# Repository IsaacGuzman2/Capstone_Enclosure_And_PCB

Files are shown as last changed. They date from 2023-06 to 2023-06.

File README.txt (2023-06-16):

Hi future student!

IF you are reading this congrats you get to continue a cool project that I had the pleasure of getting to start for my capstone.

This folder contains the enclosures and PCB files that I made for this project. I was mainly in charge of the more physical aspects of this project so any questions about that you can contact me about through my school email (guzmange@oregonstate.edu) 

I'd be more then happy to help with any questions. This stuff is free use so don't be afraid to delete, add, or modify in any way you see fit. I understand you will have to make your own engineering requirements so go off I guess. 

I wish you the best in this project don't forget to communicate with Gerrad he has some good ideas and even is really motivating. This project has some real impact so be proud of what you accomplish and relly try your best and you will be rewarded by making a positive impact in the world. 

Godspeed homies

Gerardo Isaac Guzman

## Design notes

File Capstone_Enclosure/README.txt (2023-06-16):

Hi future student! My name is Gerardo Isaac Guzman

This folder here is the solidwork files for the main enclosure that houses the microcontroller and the battery

The enclousure is printed in parts

1x bottom piece
2x latches
1x lid
1x seal

Almost all pieces are printed in PETG except for the seal which is printed in TPU

Settings for PETG
-> Temp: 230 C
-> Bed Temp: 75 C
A quick google search or youtube video for more advanced setting parameters if you want to get technical.

TPU has similar settings with a lower bed temp. I also reccommend looking up the parameters like PETG to get a more advanced print

You should be able to export the STL files for printing through solidworks. I also wanted to give you just the solid works files so you can add your own holes and other features to meet that engineering requirment quota. My group wanted to make sure you can finish the main project while still meeting the class requirements. That way capstone should be a little easier. I hope this document helps and good luck on the project, my group had a lot of fun with it and we hope you can have as much fun as well. 

Godspeed homies,

Gerardo Isaac Guzman

Email: guzmange@oregonstate.edu

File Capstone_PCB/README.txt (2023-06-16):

Hi again future student!

This here is the Kicad Project files for the Main PCB 

This PCB has the schematic and pcb files for the project as well as a folder for the gerber files to get our final version of the PCB printed by OSHPark

There should also be a .csv file here with the BOM that should help find which parts are needed in case something happens with carrying over the files. 

I HIGHLY reccomend ordering at another PCB print shop other then OSHPark because of the cost. It is a 2-layer board but it costs about $45+ with no rushed shipping (12-15 days) so it can get expensive. Please look at other options when ordering if money is an issue. 

Hopefully this file helps as always fell free to make adjustments to meet the capstone class requirements. 

Godspeed homies,

Gerardo Isaac Guzman

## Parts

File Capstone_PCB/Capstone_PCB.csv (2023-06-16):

Source: | D:\ECE441\Lab3\Capstone_PCB\Capstone_PCB.kicad_sch
Date: | 4/28/2023 10:56:03 PM
Tool: | Eeschema (6.0.8)
Generator: | D:\ECE441\Software\KiCad\6.0\bin\scripting\plugins/bom_csv_grouped_by_value.py
Component Count: | 38
Individual Components:
Item | Qty | Reference(s) | Value | LibPart | Footprint | Datasheet | MANUFACTURER | MAXIMUM_PACKAGE_HEIGHT | PARTREV | STANDARD
 |  | BATT1 | JST 2PH | Adafruit_BQ24074-eagle-import:JST_2PIN-SMT-RA | Adafruit_BQ24074:JST-PH-2-SMT-RA
 |  | C1 | 10uF | Device:C | Capacitor_SMD:C_0805_2012Metric | ~
 |  | C2 | 10uF | Device:C | Capacitor_SMD:C_0805_2012Metric | ~
 |  | C3 | 10UF | Device:C | Capacitor_SMD:C_0805_2012Metric | ~
 |  | C4 | 10UF | Device:C | Capacitor_SMD:C_0805_2012Metric | ~
 |  | C5 | 10UF | Device:C | Capacitor_SMD:C_0805_2012Metric | ~
 |  | C6 | 10UF | Device:C | Capacitor_SMD:C_0805_2012Metric | ~
 |  | C7 | 10UF | Device:C | Capacitor_SMD:C_0805_2012Metric | ~
 |  | D1 | SK34A | SK34A:SK34A | SK34A:DIOM4325X250N |  | Taiwan Semiconductor | 2.5 mm | O2102 | IPC-7351B
 |  | D2 | LED | Device:LED | LED_SMD:LED_0603_1608Metric | ~
 |  | D3 | LED | Device:LED | LED_SMD:LED_0603_1608Metric | ~
 |  | D4 | SK34A | SK34A:SK34A | SK34A:DIOM4325X250N |  | Taiwan Semiconductor | 2.5 mm | O2102 | IPC-7351B
 |  | H1 | MountingHole_Pad | Mechanical:MountingHole_Pad | MountingHole:MountingHole_2.2mm_M2_ISO14580_Pad | ~
 |  | H2 | MountingHole_Pad | Mechanical:MountingHole_Pad | MountingHole:MountingHole_2.2mm_M2_ISO14580_Pad | ~
 |  | J1 | RJ45 | Connector:RJ45 | Connector_RJ:RJ45_OST_PJ012-8P8CX_Vertical | ~
 |  | J2 | 2.1MM DC | Connector:Barrel_Jack_Switch | Connector_BarrelJack:BarrelJack_CLIFF_FC681465S_SMT_Horizontal | ~
 |  | J3 | RJ45 | Connector:RJ45 | Connector_RJ:RJ45_OST_PJ012-8P8CX_Vertical | ~
 |  | JP1 | SolderJumper_3_Bridged12 | Jumper:SolderJumper_3_Bridged12 | Jumper:SolderJumper-3_P1.3mm_Bridged12_RoundedPad1.0x1.5mm_NumberLabels | ~
 |  | JP2 | SolderJumper_3_Bridged12 | Jumper:SolderJumper_3_Bridged12 | Jumper:SolderJumper-3_P1.3mm_Bridged12_RoundedPad1.0x1.5mm | ~
 |  | JP3 | 1.5A | Jumper:SolderJumper_2_Open | Jumper:SolderJumper-2_P1.3mm_Open_TrianglePad1.0x1.5mm | ~
 |  | JP4 | 1.0A | Jumper:SolderJumper_2_Open | Jumper:SolderJumper-2_P1.3mm_Bridged_Pad1.0x1.5mm | ~
 |  | JP5 | 0.5A | Jumper:SolderJumper_2_Open | Jumper:SolderJumper-2_P1.3mm_Open_TrianglePad1.0x1.5mm | ~
 |  | JP6 | THERM | Jumper:SolderJumper_2_Open | Jumper:SolderJumper-2_P1.3mm_Bridged_RoundedPad1.0x1.5mm | ~
 |  | R1 | 10K | Device:R_Small_US | Resistor_SMD:R_0603_1608Metric | ~
 |  | R2 | 10K | Device:R_Small_US | Resistor_SMD:R_0603_1608Metric | ~
 |  | R3 | 1K | Device:R_Small_US | Resistor_SMD:R_0603_1608Metric | ~
 |  | R4 | 5.1K | Device:R_US | Resistor_SMD:R_0603_1608Metric | ~
 |  | R5 | 590 | Device:R_Small_US | Resistor_SMD:R_0603_1608Metric | ~
 |  | R6 | 1K | Device:R_Small_US | Resistor_SMD:R_0603_1608Metric | ~
 |  | R7 | 5.1K | Device:R_US | Resistor_SMD:R_0603_1608Metric | ~
 |  | R8 | 2K | Device:R_Small_US | Resistor_SMD:R_0603_1608Metric | ~
 |  | R9 | 10K | Device:R_Small_US | Resistor_SMD:R_0603_1608Metric | ~
 |  | R10 | 10K | Device:R_Small_US | Resistor_SMD:R_0603_1608Metric | ~
 |  | R11 | 10K | Device:R_Small_US | Resistor_SMD:R_0603_1608Metric | ~
 |  | SYSOUT1 | JST 2PH | Adafruit_BQ24074-eagle-import:JST_2PIN-SMT-RA | Adafruit_BQ24074:JST-PH-2-SMT-RA
 |  | U1 | BQ24074RGT | Battery_Management:BQ24074RGT | Package_DFN_QFN:VQFN-16-1EP_3x3mm_P0.5mm_EP1.6x1.6mm | http://www.ti.com/lit/ds/symlink/bq24074.pdf
 |  | X1 | USB Type C | Adafruit_BQ24074-eagle-import:USB_C | Adafruit_BQ24074:USB_C_CUSB31-CFM2AX-01-X
 |  | XA1 | Arduino_MKR_NB_1500_Socket | Arduino_Library:Arduino_MKR_NB_1500_Socket | Arduino_Library:Arduino_MKR_FOX_1200_Socket | https://docs.arduino.cc/hardware/mkr-nb-1500
Collated Components:
Item | Qty | Reference(s) | Value | LibPart | Footprint | Datasheet | MANUFACTURER | MAXIMUM_PACKAGE_HEIGHT | PARTREV | STANDARD
1 | 2 | BATT1, SYSOUT1 | JST 2PH | Adafruit_BQ24074-eagle-import:JST_2PIN-SMT-RA | Adafruit_BQ24074:JST-PH-2-SMT-RA
2 | 2 | C1, C2 | 10uF | Device:C | Capacitor_SMD:C_0805_2012Metric | ~
3 | 5 | C3, C4, C5, C6, C7 | 10UF | Device:C | Capacitor_SMD:C_0805_2012Metric | ~
4 | 2 | D1, D4 | SK34A | SK34A:SK34A | SK34A:DIOM4325X250N |  | Taiwan Semiconductor | 2.5 mm | O2102 | IPC-7351B
5 | 2 | D2, D3 | LED | Device:LED | LED_SMD:LED_0603_1608Metric | ~
6 | 2 | H1, H2 | MountingHole_Pad | Mechanical:MountingHole_Pad | MountingHole:MountingHole_2.2mm_M2_ISO14580_Pad | ~
7 | 2 | J1, J3 | RJ45 | Connector:RJ45 | Connector_RJ:RJ45_OST_PJ012-8P8CX_Vertical | ~
8 | 1 | J2 | 2.1MM DC | Connector:Barrel_Jack_Switch | Connector_BarrelJack:BarrelJack_CLIFF_FC681465S_SMT_Horizontal | ~
9 | 1 | JP1 | SolderJumper_3_Bridged12 | Jumper:SolderJumper_3_Bridged12 | Jumper:SolderJumper-3_P1.3mm_Bridged12_RoundedPad1.0x1.5mm_NumberLabels | ~
10 | 1 | JP2 | SolderJumper_3_Bridged12 | Jumper:SolderJumper_3_Bridged12 | Jumper:SolderJumper-3_P1.3mm_Bridged12_RoundedPad1.0x1.5mm | ~
11 | 1 | JP3 | 1.5A | Jumper:SolderJumper_2_Open | Jumper:SolderJumper-2_P1.3mm_Open_TrianglePad1.0x1.5mm | ~
12 | 1 | JP4 | 1.0A | Jumper:SolderJumper_2_Open | Jumper:SolderJumper-2_P1.3mm_Bridged_Pad1.0x1.5mm | ~
13 | 1 | JP5 | 0.5A | Jumper:SolderJumper_2_Open | Jumper:SolderJumper-2_P1.3mm_Open_TrianglePad1.0x1.5mm | ~
14 | 1 | JP6 | THERM | Jumper:SolderJumper_2_Open | Jumper:SolderJumper-2_P1.3mm_Bridged_RoundedPad1.0x1.5mm | ~
15 | 5 | R1, R2, R9, R10, R11 | 10K | Device:R_Small_US | Resistor_SMD:R_0603_1608Metric | ~
16 | 2 | R3, R6 | 1K | Device:R_Small_US | Resistor_SMD:R_0603_1608Metric | ~
17 | 2 | R4, R7 | 5.1K | Device:R_US | Resistor_SMD:R_0603_1608Metric | ~
18 | 1 | R5 | 590 | Device:R_Small_US | Resistor_SMD:R_0603_1608Metric | ~
19 | 1 | R8 | 2K | Device:R_Small_US | Resistor_SMD:R_0603_1608Metric | ~
20 | 1 | U1 | BQ24074RGT | Battery_Management:BQ24074RGT | Package_DFN_QFN:VQFN-16-1EP_3x3mm_P0.5mm_EP1.6x1.6mm | http://www.ti.com/lit/ds/symlink/bq24074.pdf
21 | 1 | X1 | USB Type C | Adafruit_BQ24074-eagle-import:USB_C | Adafruit_BQ24074:USB_C_CUSB31-CFM2AX-01-X
22 | 1 | XA1 | Arduino_MKR_NB_1500_Socket | Arduino_Library:Arduino_MKR_NB_1500_Socket | Arduino_Library:Arduino_MKR_FOX_1200_Socket | https://docs.arduino.cc/hardware/mkr-nb-1500

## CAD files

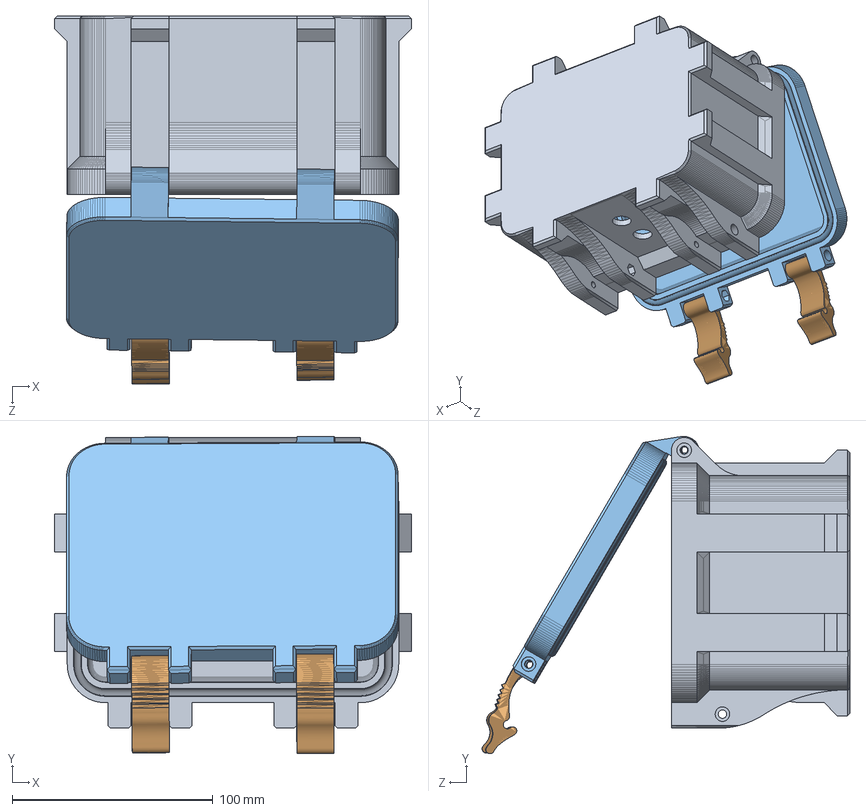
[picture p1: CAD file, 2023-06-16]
Capstone_Enclosure/Assem1.SLDASM
178.1 x 158.3 x 183.5 mm
Enclosure
Enclosure_Latch x 2
LID

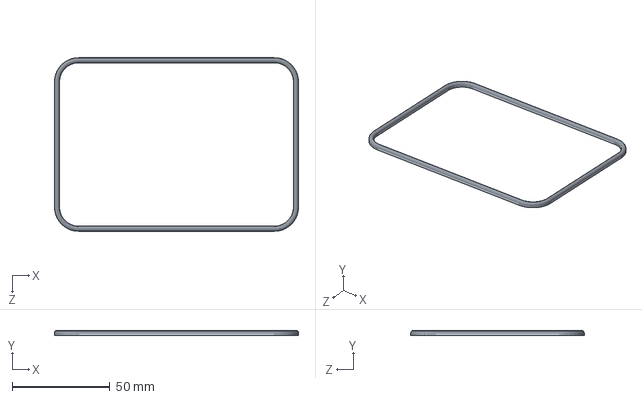
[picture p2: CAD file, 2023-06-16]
Capstone_Enclosure/SEAL.SLDPRT
124.6 x 2.80 x 88.6 mm

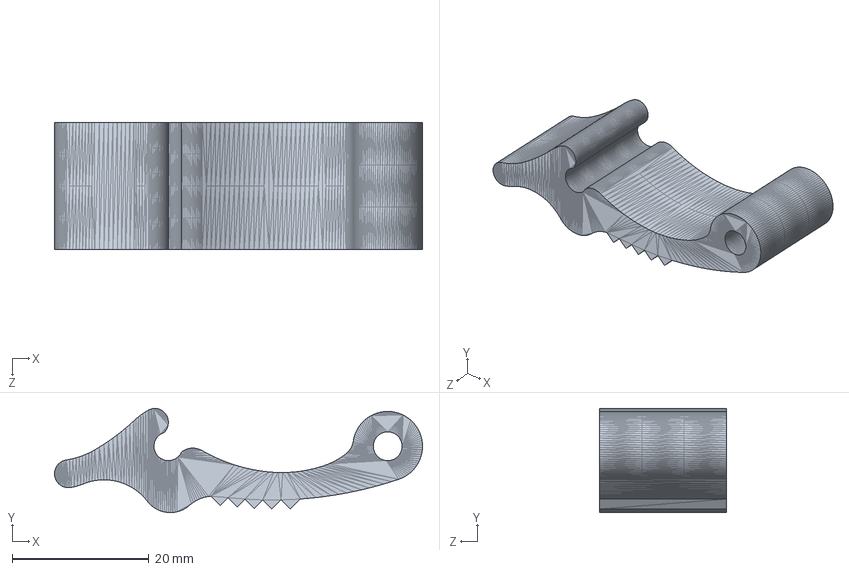
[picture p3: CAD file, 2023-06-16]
Capstone_Enclosure/Enclosure_Latch.SLDPRT
53.8 x 15.2 x 18.6 mm

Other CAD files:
Veloity Sensor Enclosure/VLCTY_SNSR_ENCL.f3d

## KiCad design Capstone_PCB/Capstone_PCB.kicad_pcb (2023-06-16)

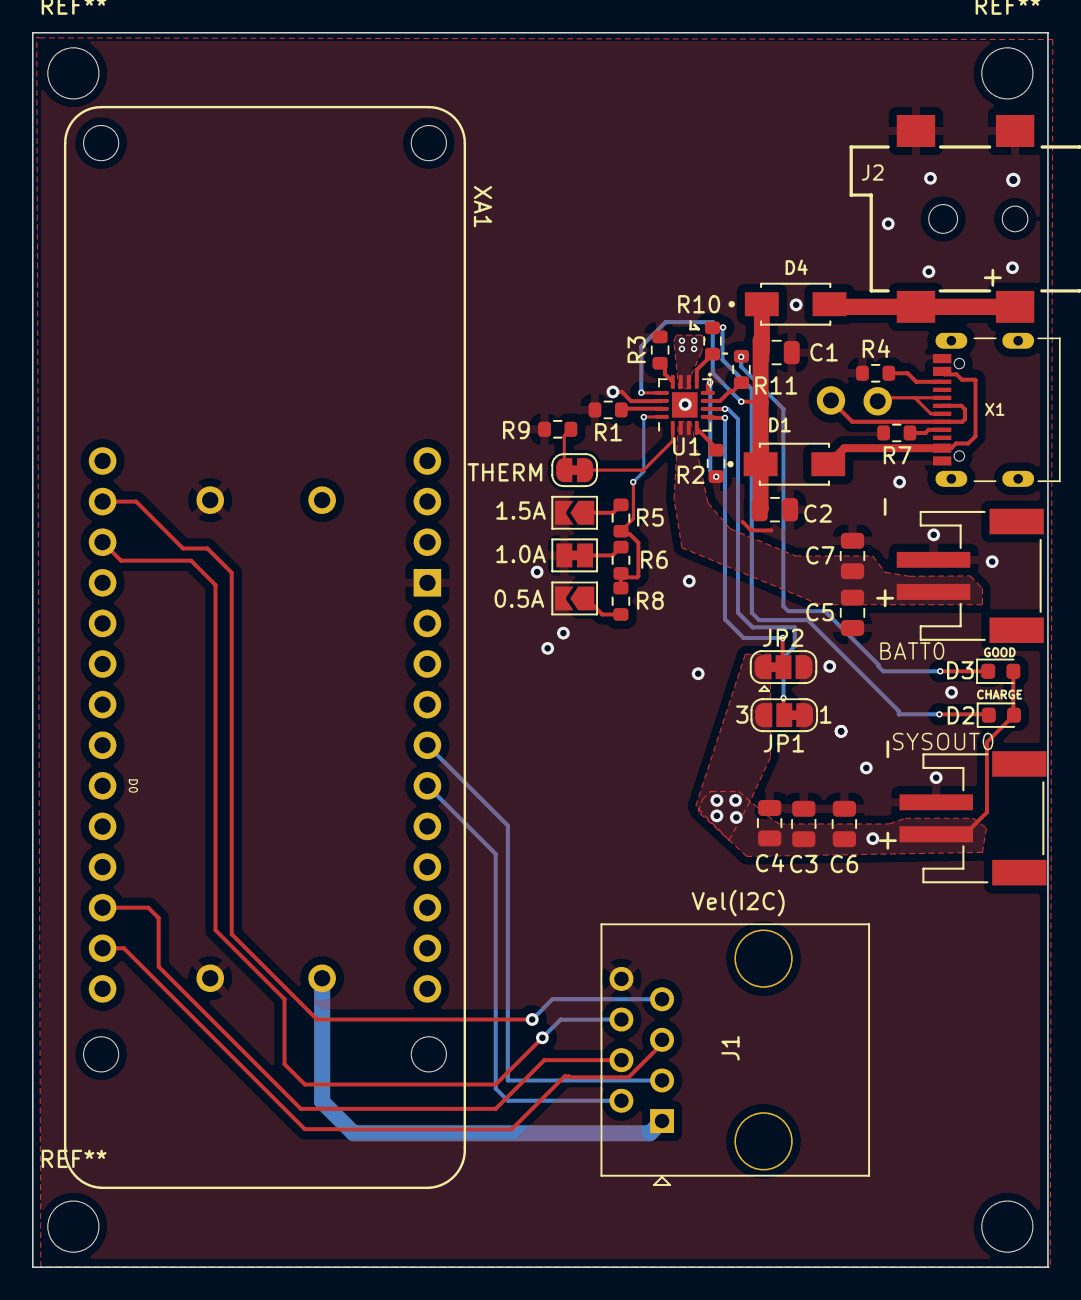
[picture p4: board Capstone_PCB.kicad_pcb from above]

Board: 2 copper layers, 63.5 x 77.2 mm, 35 parts (0 on the bottom side), 31 nets.

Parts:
BATT0: JST 2PH; JST-PH-2-SMT-RA
C1, C2: 10uF; C_0805_2012Metric
C3, C4, C5, C6, C7: 10UF; C_0805_2012Metric
D1, D4: SK34A; DIOM4325X250N
D2, D3: LED; LED_0603_1608Metric
J1: RJ45; RJ45_OST_PJ012-8P8CX_Vertical
J2: 2.1mm DC; DCJACK_2MM_SMT
JP1: SolderJumper_3_Bridged12; SolderJumper-3_P1.3mm_Bridged12_RoundedPad1.0x1.5mm_NumberL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
JP2: SolderJumper_3_Bridged12; SolderJumper-3_P1.3mm_Bridged12_RoundedPad1.0x1.5mm
JP3: 1.5A; SolderJumper-2_P1.3mm_Open_TrianglePad1.0x1.5mm
JP4: 1.0A; SolderJumper-2_P1.3mm_Bridged_Pad1.0x1.5mm
JP5: 0.5A; SolderJumper-2_P1.3mm_Open_TrianglePad1.0x1.5mm
JP6: THERM; SolderJumper-2_P1.3mm_Bridged_RoundedPad1.0x1.5mm
R1, R2, R9, R10, R11: 10K; R_0603_1608Metric
R3, R6: 1K; R_0603_1608Metric
R4, R7: 5.1K; R_0603_1608Metric
R5: 590; R_0603_1608Metric
R8: 2K; R_0603_1608Metric
SYSOUT0: JST 2PH; JST-PH-2-SMT-RA
U1: BQ24074RGT; VQFN-16-1EP_3x3mm_P0.5mm_EP1.6x1.6mm
X1: USB Type C; USB_C_CUSB31-CFM2AX-01-X
XA1: Arduino_MKR_NB_1500_Socket; Arduino_MKR_FOX_1200_Socket

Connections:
/A0: J1.7, XA1.A0 (A0/DAC)
/A1: J1.6, XA1.A1
/CC1: R7.1, X1.A5
/CC2: R4.1, X1.B5
/CE: R2.1, U1.4 (~CE)
/CHARGE: R10.2, U1.9 (~CHG)
/D3: J1.4, XA1.D3
/D4: J1.5, XA1.D4
/D+: X1.A6, X1.B6
/D-: X1.A7, X1.B7
/EN1: JP1.2 (C), U1.6 (EN1)
/EN2: JP2.2 (C), U1.5 (EN2)
/GOOD: R11.1, U1.7 (~PGOOD)
/ILIM: R3.1, U1.12 (ILIM)
/ISET: R5.1, R6.1, R8.1, U1.16 (ISET)
/ITERM: R1.1, U1.15 (ITERM)
/LIPO: BATT0.1, C5.1, C7.1, U1.2 (BAT), U1.3 (BAT)
/OUT: C3.1, C4.1, C6.1, D2.2 (A), D3.2 (A), J1.1, JP1.3 (B), JP2.1 (A), SYSOUT0.1, U1.10 (OUT), U1.11 (OUT), XA1.VIN
/SCL: J1.3, XA1.D12 (D12_SCL)
/SDA: J1.2, XA1.D11 (D11_SDA)
/TS: JP6.2 (B), U1.1 (TS)
/VIN: C1.1, C2.1, D1.C, D4.C, U1.13 (IN)
/VUSB: D1.A, X1.A4B9, X1.B4A9
GND: BATT0.2, C1.2, C2.2, C3.2, C4.2, C5.2, C6.2, C7.2, J1.8, J2.2, J2.3, JP1.1 (A), JP2.3 (B), JP3.2 (B), JP4.2 (B), JP5.2 (B), R1.2, R2.2, R3.2, R4.2, R7.2, R9.2, SYSOUT0.2, U1.8 (VSS), U1.14 (TMR), U1.17 (VSS), X1.A1B12, X1.B1A12, XA1.GND
unnamed: D2.1 (K), R10.1
unnamed: D3.1 (K), R11.2
unnamed: D4.A, J2.1, J2.1'
unnamed: JP3.1 (A), R5.2
unnamed: JP4.1 (A), R6.2
unnamed: JP5.1 (A), R8.2
unnamed: JP6.1 (A), R9.1
